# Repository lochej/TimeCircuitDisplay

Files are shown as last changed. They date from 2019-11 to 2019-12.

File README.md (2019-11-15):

# Time Circuit Display Board 

This is my version of the famous Time Circuit Display showcased in **Back to the Future** movies.

This is a piece of electronics from the *De Lorean*.
This version is 32cm in width and 7cm in height.

*So definitely not the exact same as the movie but still a nice looking piece of electronic !*

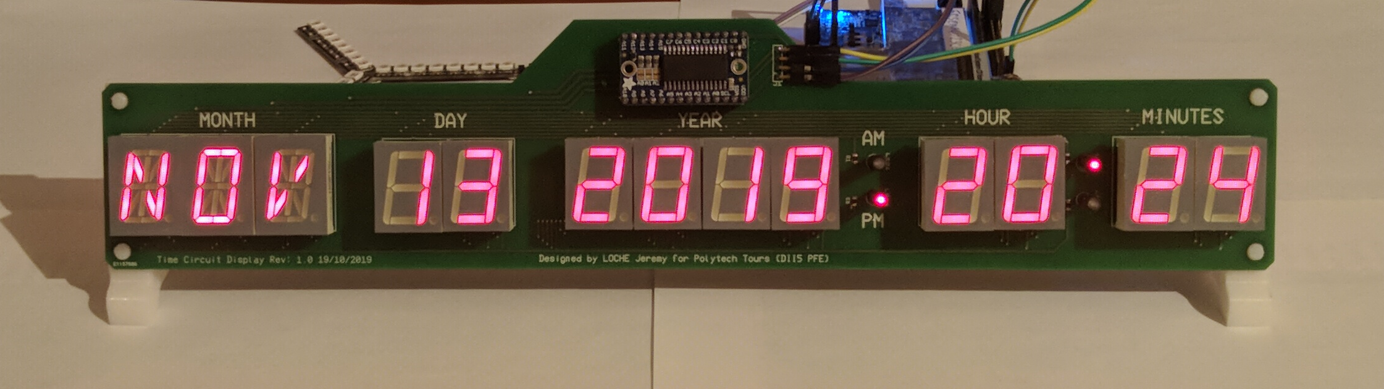
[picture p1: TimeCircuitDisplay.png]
Time Circuit Display Working


You have the hardware files for **Multisim and Ultiboard** CAD software.

**PDF are provided for documentation of the design.**

Also, I made a Library to drive the display using a Linux ARM **I2C** from userspace.

It is available in the **sw/TimeCircuitDisplay** source files.

Check it out !

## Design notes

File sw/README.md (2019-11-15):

# Driving program for Linux SBCs

This is a driving program written in ARM DS-5 IDE (Eclipse IDE with CDT extensions) and compiled with GCC 4.x minimum.

It displays current system local time using the **time.h** library and userspare **i2c driver**.

*You have to enable C dialect = C99.*

## How to compile the program

Either open the project in ARM DS-5 by setting you workspace to the **sw** folder. 
Then selecting **File->Open Project From File System** and selecting the **sw/TimeCircuitDisplay** directory.

Or compile it yourself with your prefered compiler.

## How to run the program

Connect the Time Circuit Display to you SBC i2c port.

The program uses address default 0x70 for the HT16K33 chip.
Make sure yours is set to the same, or change it in the program:

**Hint**:

In the main function, modify the **hdev.address=0** value to your A2:A1:A0 bits configured on the HT16K33 adafruit breakout.

**Program Arguments** 

1. argument 1 : 0 = turns OFF the display, 1 to 16 sets the brightness of the display, higher values will just saturate to 16.
1. argument 2 : your i2c device: if not provided by default it will use /dev/i2c-1 

**Examples:**
```
#Turn the display ON full brightness on dev i2c-0
./TimeCircuitDisplay 16 /dev/i2c-0

#This time with i2c-1
./TimeCircuitDisplay 16 /dev/i2c-1

#Turn the display OFF
./TimeCircuitDisplay 0 /dev/i2c-1
```

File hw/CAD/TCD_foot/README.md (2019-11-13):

# Time Circuit Display Foot CAD file

## What is it ?
This is the STL source file for a pretty clean and simple foot the the TimeCircuitDisplay PCB.
There is an inclination of 25° of the display so it is better readable on a table.

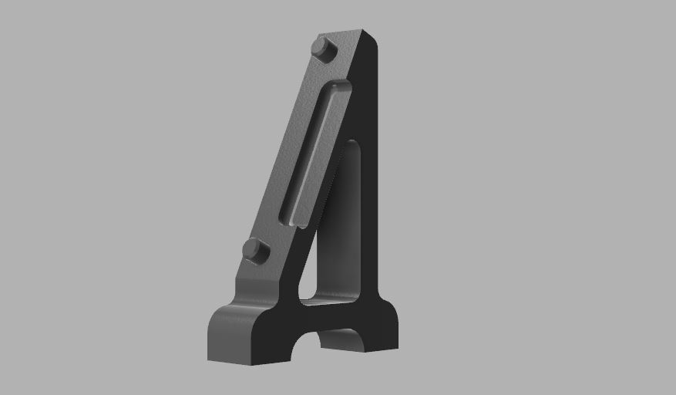
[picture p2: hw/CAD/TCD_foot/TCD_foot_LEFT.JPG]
Time Circuit Display Foot


This only is the **LEFT** foot when facing the PCB, so you need to **mirror** the part in you slicer to create the **RIGHT** foot.

**You need to do so to make sure that the grove for the 7-segments displays's pins are not in the way.**

*The part is not symmetric.*

## Printing parameters
Simply put it in you favorite slicer and print with following parameters:
1. 0.4mm nozzle width 
1. 0.2 mm layer height 
1. First layer percentage : 110%
1. Infill : Cubic 20%
1. 3 perimeter walls
1. 3 top and bottom layers

*Print it flat to save on support !*
This part is a **tight fit** and should not require any glue to stay fixed on the PCB.

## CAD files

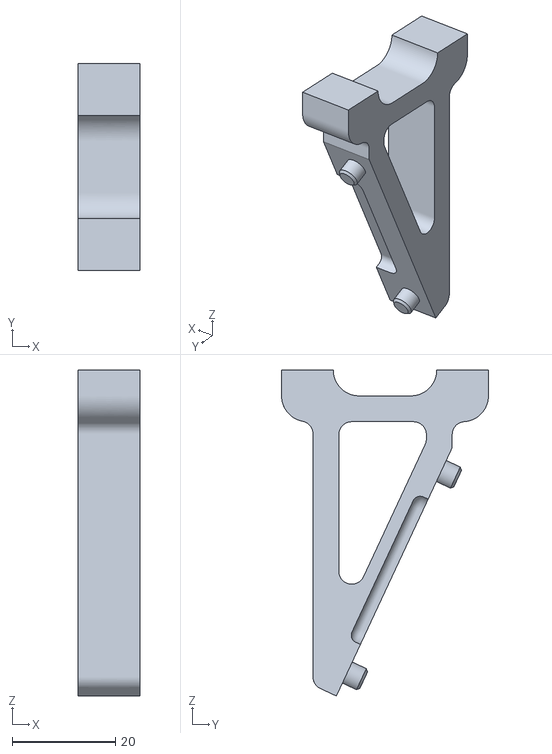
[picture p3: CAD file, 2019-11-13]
hw/CAD/TCD_foot/TCD_foot_LEFT.stl
12.0 x 40.0 x 63.0

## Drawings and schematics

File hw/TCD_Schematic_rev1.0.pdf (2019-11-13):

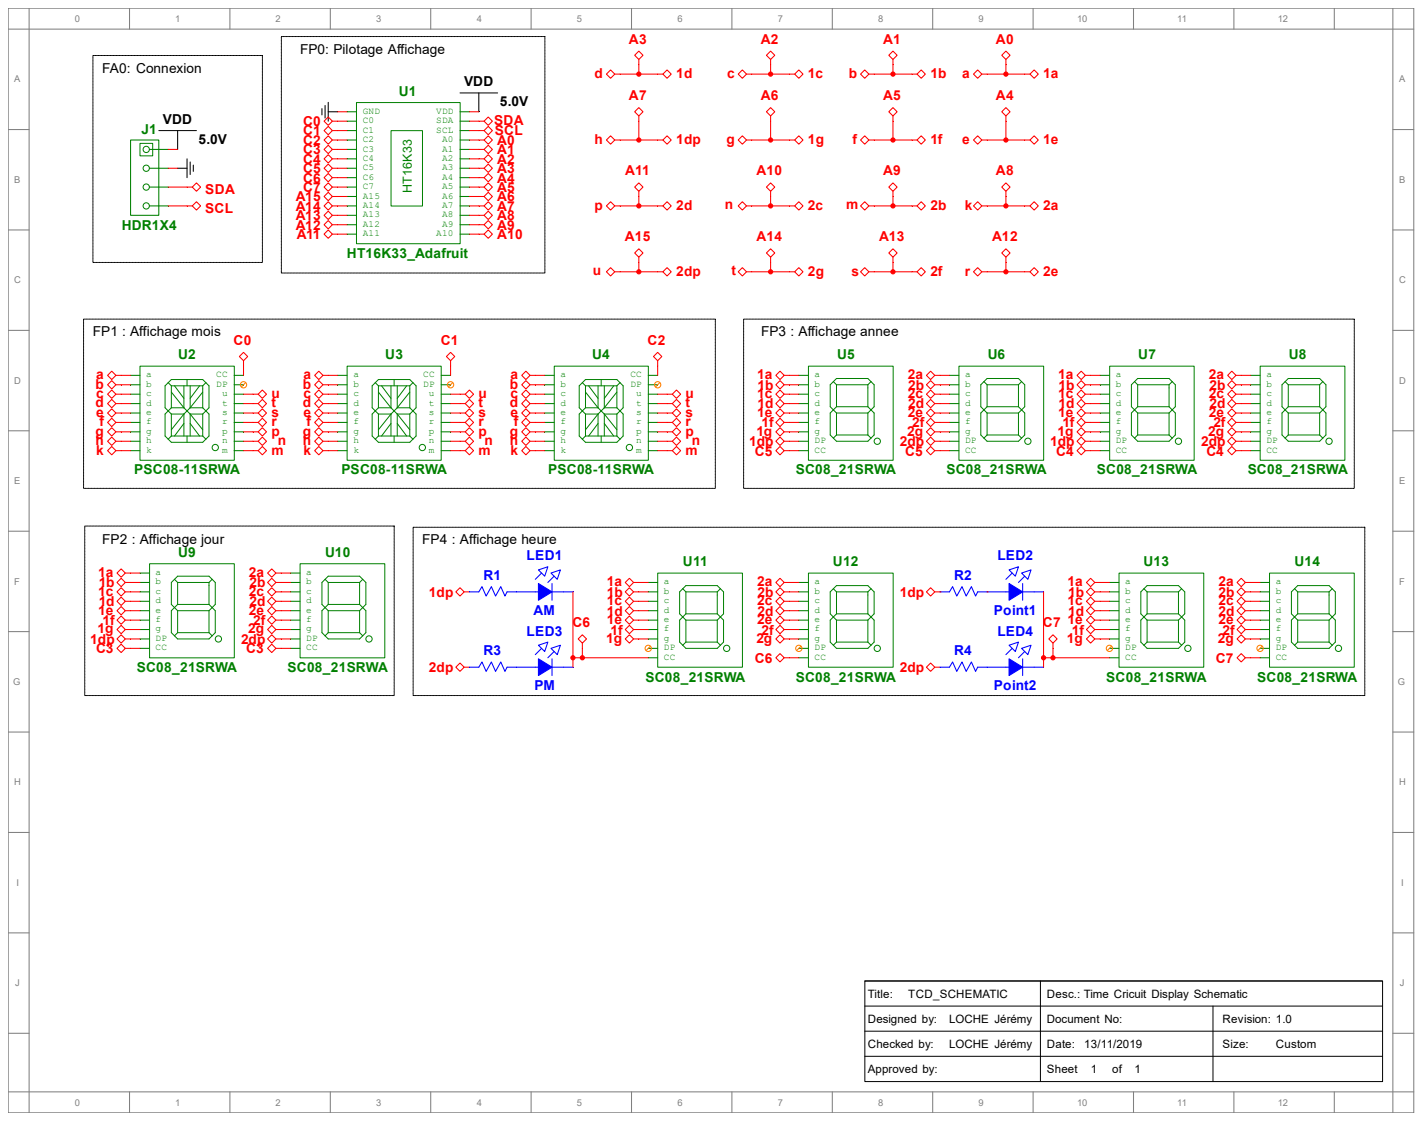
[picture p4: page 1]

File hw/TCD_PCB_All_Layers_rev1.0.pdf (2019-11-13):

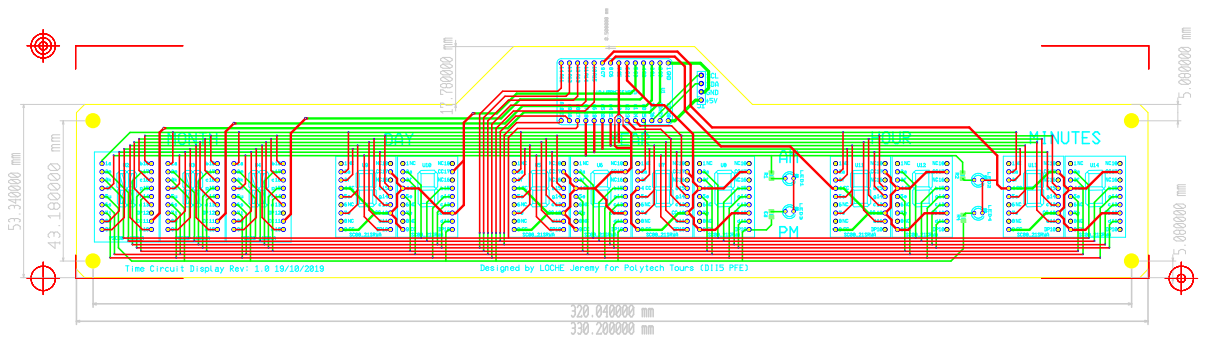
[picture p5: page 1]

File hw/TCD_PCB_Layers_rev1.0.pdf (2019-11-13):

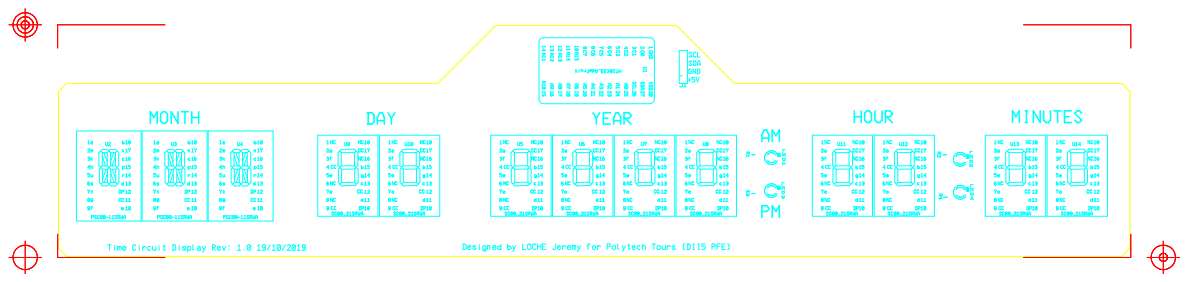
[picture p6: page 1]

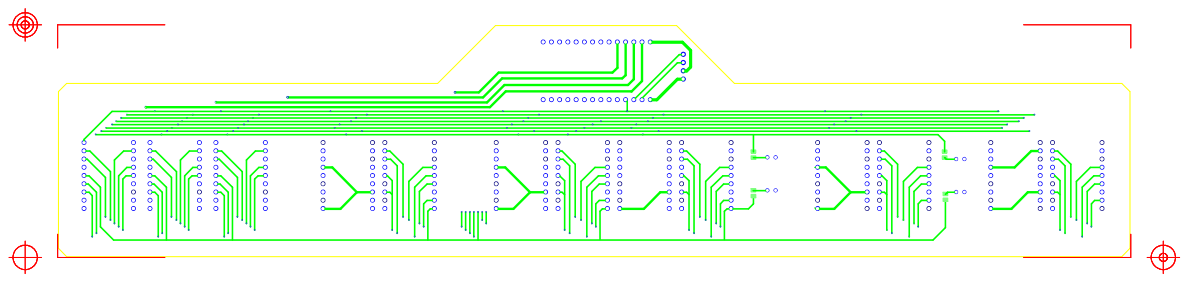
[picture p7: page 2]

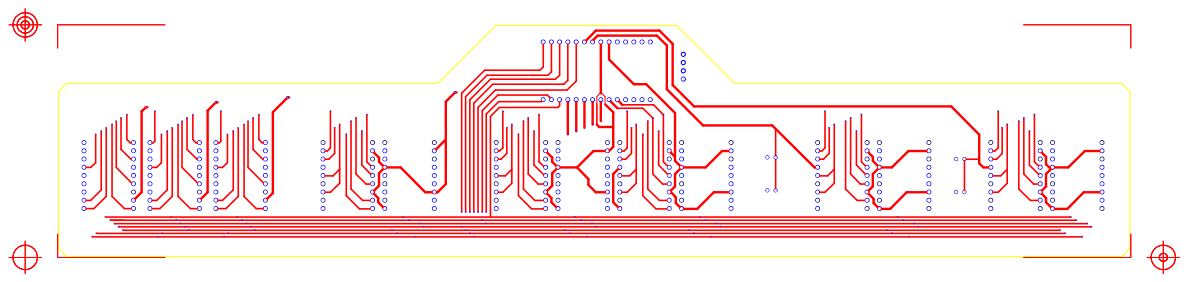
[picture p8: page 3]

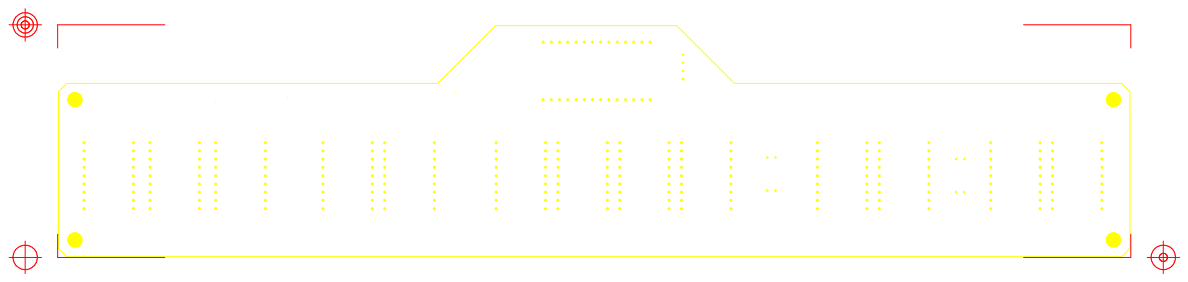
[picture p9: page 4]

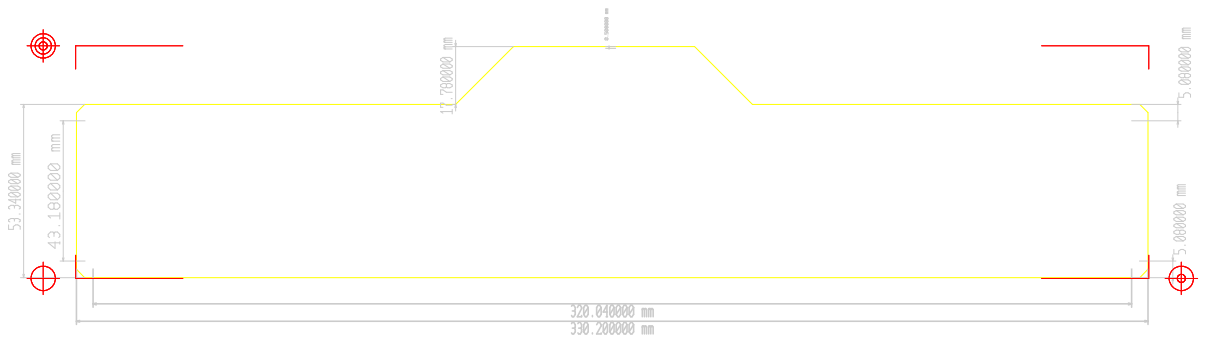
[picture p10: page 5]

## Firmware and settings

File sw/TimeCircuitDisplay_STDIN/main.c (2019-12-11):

/*
 * main.c
 *
 *  Created on: Oct 24, 2019
 *      Author: fpga
 */
#include <stdio.h>
#include <stdlib.h>
#include <unistd.h>
#include <time.h>
#include "timecircuitdisplay.h"
#include <sys/select.h>

//Conflicts with IOCTL
#define MAX_NB_ERRORS_IOCTL 1
#define MAX_NB_ERRORS_I2C 5
#define TIMEOUT_SEC_NO_ERROR_COUNTER_RESET 10

#define REFRESH_PERIOD_MS 250
ht16k33_t hdev={0};
timecircuit_t htcd={0};
uint8_t cnt_hours=88; //set all default values to 88, ensures a first set in the while loop.
uint8_t cnt_minutes=88;
uint8_t cnt_days=88;
uint8_t cnt_months=88;
uint16_t cnt_year=8888;
uint8_t cnt_seconds=0;
uint16_t cnt_ms=0;
uint8_t brightness=0;


/**
 * Prints an error message and its result code and exiting the software with specified exit code
 * @param cause_msg
 * @param cause_result_code
 * @param exit_code
 */
void errorExit(char * cause_msg, int cause_result_code,int exit_code)
{
	if(cause_result_code)
	{
		printf("Fatal error cause exit : %s with res_code:%d\n",cause_msg,cause_result_code);
		exit(exit_code);
	}
}

/**
 * Checks and counts errors on the TCD commands. If too many I2C errors or IOCTL errors occur, then the program will exit with an error.
 * @param cause_msg
 * @param cause_result_code
 */
void check_tcd_errors(char * cause_msg,int cause_result_code)
{
	static uint8_t ioctl_error_count=0;
	static uint8_t i2c_write_error_count=0;

	static time_t last_error_time=0;
	//static uint8_t first_check=1;

	//Not robust to change in date of the system ?
#if 0
	//first call of the function, init last_error_time;
	if(first_check){
		first_check=0;
		last_error_time=time(NULL);
	}

	//If it has been more than 10 seconds without i2c errors, reset the counter.
	if(time(NULL) - last_error_time >= TIMEOUT_SEC_NO_ERROR_COUNTER_RESET)
	{
		last_error_time=time(NULL);
		i2c_write_error_count=0;
		ioctl_error_count=0;
	}
#endif

	//No errors
	if(cause_result_code==0)
		return;

	switch(cause_result_code)
	{
	case -1: //IOCTL acquire errors
		ioctl_error_count++;

		//register error our and date
		last_error_time=time(NULL);

		printf("Error %d/%d IOCTL acquire registered for %s with code=%d\n",ioctl_error_count,MAX_NB_ERRORS_IOCTL,cause_msg,cause_result_code);
		printf("Is it a /dev/i2c-* device ?\n");

		if(ioctl_error_count >= MAX_NB_ERRORS_IOCTL){
			printf("Reached max IOCTL errors\n");
			errorExit(cause_msg, cause_result_code, EXIT_FAILURE);
			return;
		}

		break;
	case -2: //I2C write failed, because no component responding ACK on the line
		i2c_write_error_count++;

		//register error our and date
		last_error_time=time(NULL);

		printf("Error %d / %d I2C write registered for %s with code=%d\n",i2c_write_error_count,MAX_NB_ERRORS_I2C,cause_msg,cause_result_code);

		if(i2c_write_error_count >= MAX_NB_ERRORS_I2C){
			printf("Reached max I2C write errors\n");
			errorExit(cause_msg, cause_result_code, EXIT_FAILURE);
			return;
		}

		break;
	case -3: //I2C not the correct amount of bytes written to I2C. Possibly a programming error.
		printf("Error I2C not write correct nb of bytes for %s with code=%d\n",cause_msg,cause_result_code);
		errorExit(cause_msg, cause_result_code, EXIT_FAILURE);
		break;
	}
}

//Data is to be read from stdin
int check_stdin()
{
	// if != 0, then there is data to be read on stdin
	// timeout structure passed into select
	struct timeval tv;
	// fd_set passed into select
	fd_set fds;
	// Set up the timeout.  here we can wait for 1 second
	tv.tv_sec = 0;
	tv.tv_usec = REFRESH_PERIOD_MS*1000;

	// Zero out the fd_set - make sure it's pristine
	FD_ZERO(&fds);
	// Set the FD that we want to read
	FD_SET(STDIN_FILENO, &fds); //STDIN_FILENO is 0
	// select takes the last file descriptor value + 1 in the fdset to check,
	// the fdset for reads, writes, and errors.  We are only passing in reads.
	// the last parameter is the timeout.  select will return if an FD is ready or
	// the timeout has occurred
	if(select(STDIN_FILENO+1, &fds, NULL, NULL, &tv)==-1)
	{
		printf("Error occured in Select\n");
	}

	usleep(tv.tv_usec);
	// return 0 if STDIN is not ready to be read.
	return FD_ISSET(STDIN_FILENO, &fds);
}

void read_brightness(){

	char buffer[10];
	int res;
	res=read(STDIN_FILENO, buffer, 10);

	if(res<0){
		//error
		printf("Error on stdin read\n");
		return;
	}
	else if(res>0)
	{
		buffer[res-1]='\0';
		int value= strtol(buffer,NULL,10);

		ht16k33_setBrightness(&hdev, value);
		printf("Read %s -> %d\n",buffer,value);
	}

}

/**
 * Time Circuit Display with arguments
 * @param argc
 * @param argv
 * @return
 */
int main(int argc,char ** argv)
{
	int res;
	printf("Time Circuit Display driving program\n");

	//Check for program arguments
	if(argc < 2){
		printf("Usage is : argv[1]=brightness optionnal argv[2]=i2c_dev file\n");
		printf("Brightness value of 0 means display OFF\n");
		printf("Brightness value of 1 (min) to 16 (max) starts the display with brightness\n");
		printf("i2c file should be provided as parameter 2, if not /dev/i2c-1 will be chosen\n");
		return -1;
	}

	//Parse brightness
	if(argc > 1){
		brightness=(uint8_t) strtol(argv[1],NULL,10);
	}
	else{
		brightness=16;
	}

	hdev.address=0; //Change to the A2:A1:A0 bits of your Time circuit
	hdev.i2c_dev_file= argc >= 3 ? argv[2] : "/dev/i2c-1";

	htcd.ht16k33_dev=&hdev;

	res = tcd_init(&htcd); //could crash because i2c file open failed, couldn't write to device,

	check_tcd_errors("tcd_init()", res);

	if(brightness == 0){
		ht16k33_displayOn(&hdev, brightness == 0 ? 0 : 1);
		printf("Turning display OFF\n");
		exit(EXIT_SUCCESS);
	}

	/*
	tcd_setDays(&htcd,cnt_days);
	tcd_setMonth(&htcd,cnt_months,TCD_MONTH_ASCII);
	tcd_setYear(&htcd,cnt_year);
	tcd_setHoursMinutes(&htcd,cnt_hours,cnt_minutes);
	tcd_setDots(&htcd,cnt_seconds);
	tcd_setAMPM(&htcd,0);
	 */
	printf("Turning display ON\n");
	printf("Setting TCD brightness to %d\n",brightness);

	res = ht16k33_setBrightness(htcd.ht16k33_dev, brightness-1);

	errorExit("ht16k33_setBrightness() failed", res, EXIT_FAILURE);


	printf("Displaying time every %d ms\n",REFRESH_PERIOD_MS);

	time_t now=time(NULL);
	struct tm * time_fields;

	while(1)
	{
		now=time(NULL);
		time_fields=localtime(&now);

		if(cnt_days != time_fields->tm_mday)
		{

			res=tcd_setDays(&htcd,time_fields->tm_mday);

			check_tcd_errors("tcd_setDays()", res);

			//Applied days correctly
			if(!res)
				cnt_days=time_fields->tm_mday;

		}

		if(cnt_months!=time_fields->tm_mon+1)
		{

			res=tcd_setMonth(&htcd,time_fields->tm_mon+1,TCD_MONTH_ASCII);

			check_tcd_errors("tcd_setMonth()",res);

			if(!res)
				cnt_months=time_fields->tm_mon+1;


		}

		if(cnt_year!=(time_fields->tm_year+1900))
		{

			res=tcd_setYear(&htcd,(time_fields->tm_year+1900));

			check_tcd_errors("tcd_setYear()",res);

			if(!res)
				cnt_year=time_fields->tm_year+1900;


		}

		if(cnt_hours!=time_fields->tm_hour)
		{

			res=tcd_setHours(&htcd, time_fields->tm_hour);

			check_tcd_errors("tcd_setHours()",res);
			if(!res)
				cnt_hours=time_fields->tm_hour;



			res=tcd_setAMPM(&htcd, cnt_hours > 12 ? 0x2: 0x1);

			check_tcd_errors("tcd_setAMPM()",res);
		}

		if(cnt_minutes!=time_fields->tm_min)
		{

			res=tcd_setMinutes(&htcd, time_fields->tm_min);

			if(!res)
				cnt_minutes=time_fields->tm_min;

			check_tcd_errors("tcd_setMinutes()",res);
		}

		if(cnt_seconds != time_fields->tm_sec)
		{
			cnt_ms=0;
			cnt_seconds=time_fields->tm_sec;
			//tcd_setDots(&htcd,cnt_seconds);
			//tcd_setAMPM(&htcd,cnt_seconds);
		}

		res=tcd_setDots(&htcd,cnt_ms/REFRESH_PERIOD_MS);

		check_tcd_errors("tcd_setDots()",res);

		//usleep(REFRESH_PERIOD_MS*1000);

		/** Read stdin to check for new birghtness value */
		if(check_stdin())
		{
			read_brightness();
		}


		cnt_ms+=REFRESH_PERIOD_MS;
	}

	return 0;
}

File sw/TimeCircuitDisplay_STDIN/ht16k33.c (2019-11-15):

/*
 * ht16k33.c
 *
 *  Created on: 13 oct. 2019
 *      Author: JLH
 */

#include "ht16k33.h"
#include <stdio.h>
#include <sys/ioctl.h>			//Needed for I2C port
#include <linux/i2c-dev.h>
#include <unistd.h>				//Needed for I2C port
#include <fcntl.h>


/**
 * Init the ht16k33 device using the provided device structure
 * @param dev
 * @return
 *  0 = SUCCESS,
 * -1 = I2C_IOCTL_ACQUIRE_FAILED,
 * -2 = I2C_COULDNT_WRITE,
 * -3 = I2C_NOT_CORRECT_NB_OF_BYTES_WRITTEN
 * -6 = I2C_FILE is NULL
 * -7 = COULDNT OPEN I2C FILE
 */
int8_t ht16k33_init(ht16k33_t * dev)
{
	int res;
	//----- OPEN THE I2C BUS -----
	if(dev->i2c_dev_file == NULL)
	{
		printf("i2c file name is NULL, can't init\n");
		return -6;
	}

	if ((dev->i2c_fd = open(dev->i2c_dev_file, O_RDWR)) < 0)
	{
		//ERROR HANDLING: you can check errno to see what went wrong
		printf("Failed to open the i2c bus %s\n",dev->i2c_dev_file);
		return -7;
	}

	//memset(dev->ram_data,0x00,HT16K33_RAM_SIZE);

	res=ht16k33_systemStandby(dev, HT16K33_CMD_SYSTEM_SETUP_NORMAL);
	if(res) return res;

	res=ht16k33_writeCommand(dev, HT16K33_CMD_ROWINT_OUTPUT);
	if(res) return res;

	res=ht16k33_setBrightness(dev,0xF);
	if(res) return res;

	res=ht16k33_displaySetup(dev, HT16K33_DISPLAY_OFF, HT16K33_BLINK_OFF);
	if(res) return res;

	res=ht16k33_writeRAM_N(dev, HT16K33_RAM_START, HT16K33_RAM_SIZE);
	if(res) return res;

	res=ht16k33_displayOn(dev, HT16K33_DISPLAY_ON);
	if(res) return res;

	return 0;
}

/**
 * Sets the a single pixel in the local ht16k33 buffer row pin and com pin
 * @param dev
 * @param row : row between 0 and 15
 * @param column : column between 0 and 7
 * @return 0 = SUCCESS, -1 = pixel coordinates out of range
 */
int8_t ht16k33_setPixel(ht16k33_t * dev,uint8_t row, uint8_t column,uint8_t state)
{
	if(row >= 16 || column >=8)
		return -1;

	uint8_t ram_id=column*2 + (row > 7 ? 1:0);
	uint8_t ram_off=(row > 7 ? row-8 : row);

	if(state) dev->ram_data[ram_id] |= (1<<ram_off);
	else dev->ram_data[ram_id] &= ~(1<<ram_off);

	return 0;
}

/**
 * Sets the whole local ht16k33 buffer row for the given com pin
 * @param dev
 * @param row : 16 bits ROW value
 * @param com : given com
 * @return 0 = SUCCESS, -1 = COM is out of range
 */
int8_t ht16k33_setRow(ht16k33_t *dev,uint16_t row,uint8_t com)
{
	if(com >= 8)
		return -1;
	dev->ram_data[com*2 + 1]=row>>8;
	dev->ram_data[com*2]=row & 0xFF;
	return 0;
}

/**
 * Sets the HT16k33 brightness value
 * @param dev
 * @param dim : 0 = minimum brightness to 15 = maximum brightness
 * @return error_code :
 *  0 = SUCCESS,
 * -1 = I2C_IOCTL_ACQUIRE_FAILED,
 * -2 = I2C_COULDNT_WRITE,
 * -3 = I2C_NOT_CORRECT_NB_OF_BYTES_WRITTEN
 */
int8_t ht16k33_setBrightness(ht16k33_t * dev,uint8_t dim)
{
	int8_t res;

	if(dim > 0xF)
		dim=0xF;

	res=ht16k33_writeCommand(dev,HT16K33_REG_DIMMING_BASE | dim);
	if(res)
		return res;

	HT16K33_STATUS_SET_BRIGHTNESS(dev->status,dim);
	return res;
}

/**
 * Sets the HT16k33 display setup, ON and BLINK settings
 * @param dev
 * @param on : true = display ON, false = display OFF
 * @param blink : HT16K33_BLINK_OFF=0, HT16K33_BLINK_2HZ=1, HT16K33_BLINK_1HZ=2, HT16K33_BLINK_05HZ=3
 * @return error_code :
 *  0 = SUCCESS,
 * -1 = I2C_IOCTL_ACQUIRE_FAILED,
 * -2 = I2C_COULDNT_WRITE,
 * -3 = I2C_NOT_CORRECT_NB_OF_BYTES_WRITTEN
 */
int8_t ht16k33_displaySetup(ht16k33_t * dev,uint8_t on,uint8_t blink)
{
	int8_t res;

	blink &=0x03; //Make sure blink is only 2 LSB

	uint8_t display_setup=HT16K33_CMD_DISPLAY_SETUP(
			on ? HT16K33_DISPLAY_ON : HT16K33_DISPLAY_OFF,
					blink);

	res=ht16k33_writeCommand(dev,display_setup);

	if(res)
		return res;

	HT16K33_STATUS_SET_BLINK(dev->status,blink);
	HT16K33_STATUS_SET_ON(dev->status,on ? HT16K33_DISPLAY_ON:HT16K33_DISPLAY_OFF);

	return 0;
}

/**
 * Sets the HT16k33 operating mode, NORMAL or STANDBY
 * @param dev
 * @param mode : mode to set
 * @return error_code :
 *  0 = SUCCESS,
 * -1 = I2C_IOCTL_ACQUIRE_FAILED,
 * -2 = I2C_COULDNT_WRITE,
 * -3 = I2C_NOT_CORRECT_NB_OF_BYTES_WRITTEN
 * -4 = MODE is not HT16K33_CMD_SYSTEM_SETUP_NORMAL or HT16K33_CMD_SYSTEM_SETUP_STANDBY
 */
int8_t ht16k33_systemStandby(ht16k33_t * dev,uint8_t mode)
{
	int8_t res;

	if(!(mode == HT16K33_CMD_SYSTEM_SETUP_NORMAL || mode == HT16K33_CMD_SYSTEM_SETUP_STANDBY))
		return -4;

	res=ht16k33_writeCommand(dev, mode);

	if(res)
		return res;

	HT16K33_STATUS_SET_STANDBY(dev->status,HT16K33_CMD_SYSTEM_SETUP_NORMAL ? 0:1);

	return 0;
}

//Inlined in header file
#if 0
int8_t ht16k33_displayOn(ht16k33_t * dev,uint8_t on)
{
	return ht16k33_displaySetup(dev, on, HT16K33_STATUS_GET_BLINK(dev->status));
}

int8_t ht16k33_blink(ht16k33_t * dev,uint8_t blink)
{
	return ht16k33_displaySetup(dev, HT16K33_STATUS_GET_BLINK(dev->status), blink);
}
#endif

//Pilotage bas niveau

/**
 * Updates the nb RAM bytes from dev struct to the HT16K33
 * @param dev :
 * @param from_addr : ram bytes address from 0 to 15
 * @param nb : number of bytes to write
 * @return error_code :
 *  0 = SUCCESS,
 * -1 = I2C_IOCTL_ACQUIRE_FAILED,
 * -2 = I2C_COULDNT_WRITE,
 * -3 = I2C_NOT_CORRECT_NB_OF_BYTES_WRITTEN
 * -4 = from_addr exceeds ram size
 * -5 = from_addr + nb will exceed ram size
 */
int8_t ht16k33_writeRAM_N(ht16k33_t * dev,uint8_t from_addr, uint8_t nb)
{

	int8_t res=0;

	if(from_addr >= HT16K33_RAM_SIZE) //too far in the buffer
		return -4;

	if((from_addr + nb) > HT16K33_RAM_SIZE) //will overflow buffer
		return -5;


	res=ht16k33_writeRegs(dev, HT16K33_REG_DISPLAY_DATA_RAM_BASE+from_addr,&(dev->ram_data[from_addr]),nb);
	if(res)
		return res;

	return res;
}

/**
 * Updates the nb RAM bytes from HT16K33 to the dev struct
 * @param dev :
 * @param from_addr : ram bytes address from 0 to 15
 * @param nb : number of bytes to write
 * @return error_code:
 *  0 = SUCCESS,
 * -1 = I2C_IOCTL_ACQUIRE_FAILED,
 * -2 = I2C_COULDNT_WRITE,
 * -3 = I2C_NOT_CORRECT_NB_OF_BYTES_WRITTEN
 * -4 = from_addr exceeds ram size
 * -5 = from_addr + nb will exceed ram size
 */
int8_t ht16k33_readRAM_N(ht16k33_t * dev,uint8_t from_addr, uint8_t nb)
{
	int8_t res=0;

	if(from_addr >= HT16K33_RAM_SIZE) //too far in the buffer
		return -4;

	if((from_addr + nb) > HT16K33_RAM_SIZE) //will overflow buffer
		return -5;


	res=ht16k33_readRegs(dev, HT16K33_REG_DISPLAY_DATA_RAM_BASE+from_addr,(dev->ram_data) + from_addr,nb);
	if(res)
		return res;

	return res;
}

/**
 * Updates the RAM bytes from_addr to to_addr dev struct to the HT16K33
 * @param dev :
 * @param from_addr :first ram address inclusive
 * @param to_addr : last ram address inclusive
 * @return error_code :
 *  0 = SUCCESS,
 * -1 = I2C_IOCTL_ACQUIRE_FAILED,
 * -2 = I2C_COULDNT_WRITE,
 * -3 = I2C_NOT_CORRECT_NB_OF_BYTES_WRITTEN
 * -4 = from_addr exceeds ram size
 * -5 = from_addr is equal or superior to to_addr
 */
int8_t ht16k33_writeRAM(ht16k33_t * dev,uint8_t from_addr, uint8_t to_addr)
{
	if(from_addr >= to_addr)
		return -5;
	return ht16k33_writeRAM_N(dev, from_addr, to_addr - from_addr);
}
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

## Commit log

2019-11-13 Added source files and README
    [TCD_SHM_0 - Board Outline.gbr, TCD_SHM_0 - Copper Bottom.gbr, TCD_SHM_0 - Copper Top-Copper Bottom.drl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]
2019-11-13 Added Time Circuit Display foot CAD file
    [TCD_foot_LEFT.stl]
2019-11-13 Added the time circuit display photo to README
2019-11-15 Adding more doxygen to functions and more error checking
    [ht16k33.c, main.c]
2019-11-17 Changed initialization values for tcd to avoid hours and minutes not beeing set program start
    [main.c]
